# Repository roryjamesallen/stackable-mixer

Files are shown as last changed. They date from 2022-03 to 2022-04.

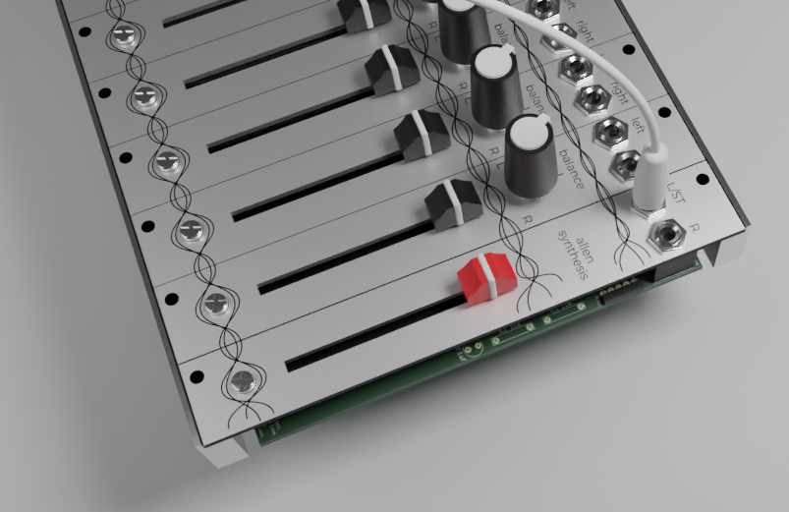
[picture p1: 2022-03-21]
extras/render.png

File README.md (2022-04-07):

# stackable-mixer
A versatile, affordable, free hardware, stereo mixer for Eurorack


  
Each input channel has either mono or stereo inputs, a balance control, a mute switch, and a volume control.
The output stage has a stereo TRS (headphone) output, but patching into the right input will break the normalling, allowing you to output stereo over two mono cables.
The output also has a mute switch and volume control, so you can easily mute your system or adjust the master volume depending on where your output is going.
  
Each input channel is passive, so can be made very affordably, although ±12V and Earth are available from the bus which carries the stereo signals, so future/user-developed input stages could be active, for example an input stage with an active EQ.
  
There is also of course the potential for alternative output stages, such as balanced 6.35mm or separate output and monitor outputs for headphone monitoring during a live set.

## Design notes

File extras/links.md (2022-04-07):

[female header](https://www.toby.co.uk/board-to-board-pcb-connectors/200mm-sockets/b13a-valcon-2mm-single-row-right-angle-socket-strip-43mm-profile/)

[slide potentiometer](https://www.mouser.co.uk/ProductDetail/Bourns/PTA4544-2010DPA103?qs=U%2FacTlguYxa%252BzXWV0%2FTcHg%3D%3D)

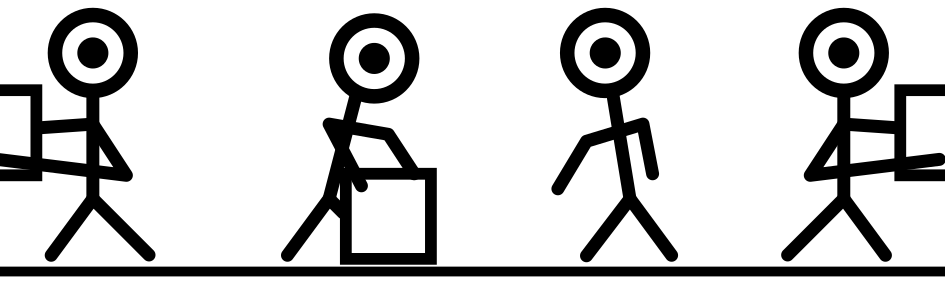
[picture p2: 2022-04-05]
extras/artwork/.svg2shenzhen-cache/images/F.SilkS_layer1.png

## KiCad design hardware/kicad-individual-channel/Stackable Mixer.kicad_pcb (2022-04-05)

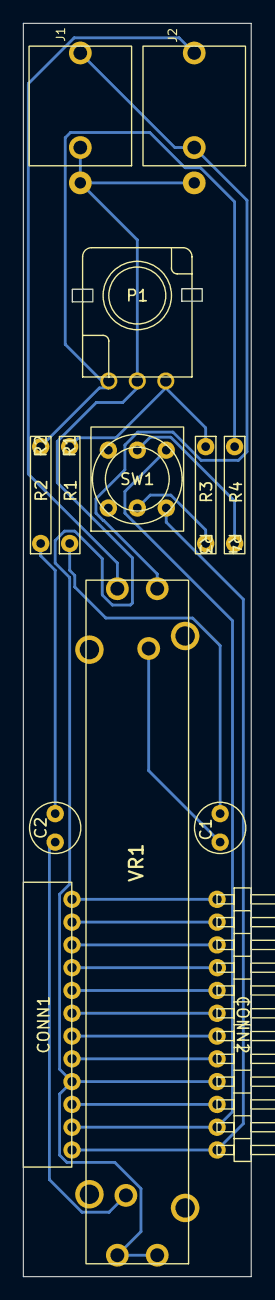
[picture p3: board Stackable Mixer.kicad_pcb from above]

Board: 2 copper layers, 20.0 x 110.0 mm, 13 parts (0 on the bottom side), 22 nets.

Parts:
C1, C2: 100nF; Capacitor Small Non-Polarised
CONN1: Header_2.0mm_Right_Angle_Female; Header 01x12 2.0mm Right Angle Female
CONN2: Header_2.0mm_Right_Angle_Male; Header 01x12 2.0mm Right Angle Male
J1: L/Mono; Thonkiconn Mono Jack
J2: R; Thonkiconn Mono Jack
P1: Potentiometer_9mm_Vertical_Linear; Potentiometer 9mm Vertical Linear
R1, R2: 100k; Resistor 0.25W Through-Hole
R3, R4: 4.7k; Resistor 0.25W Through-Hole
SW1: SW_DPDT_x2; Sub-Miniature Toggle Switch DPDT
VR1: Potentiometer_45mm_Slide_Audio_Dual; Potentiometer 45mm Slide Audio

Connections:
/+12V: CONN1.5, CONN2.8
/-12V: CONN1.3, CONN2.10
/LEFT BUS: CONN1.1, CONN2.12, SW1.1 (A)
/LEFT SIGNAL: R3.2, SW1.2 (B)
/RIGHT BUS: CONN1.2, CONN2.11, SW1.4 (A)
/RIGHT SIGNAL: R4.2, SW1.5 (B)
Earth: CONN1.4, CONN2.9, J1.1 (E), J1.2 (S), J2.1 (E), P1.2, VR1.1, VR1.4
unnamed: C1.1, VR1.5
unnamed: C1.2, R1.1
unnamed: C2.1, VR1.2
unnamed: C2.2, R2.1
unnamed: CONN1.6, CONN2.7
unnamed: CONN1.7, CONN2.6
unnamed: CONN1.8, CONN2.5
unnamed: CONN1.9, CONN2.4
unnamed: CONN1.10, CONN2.3
unnamed: CONN1.11, CONN2.2
unnamed: CONN1.12, CONN2.1
unnamed: J1.3 (T), J2.2 (S), VR1.6
unnamed: J2.3 (T), VR1.3
unnamed: P1.1, R2.2, R4.1
unnamed: P1.3, R1.2, R3.1

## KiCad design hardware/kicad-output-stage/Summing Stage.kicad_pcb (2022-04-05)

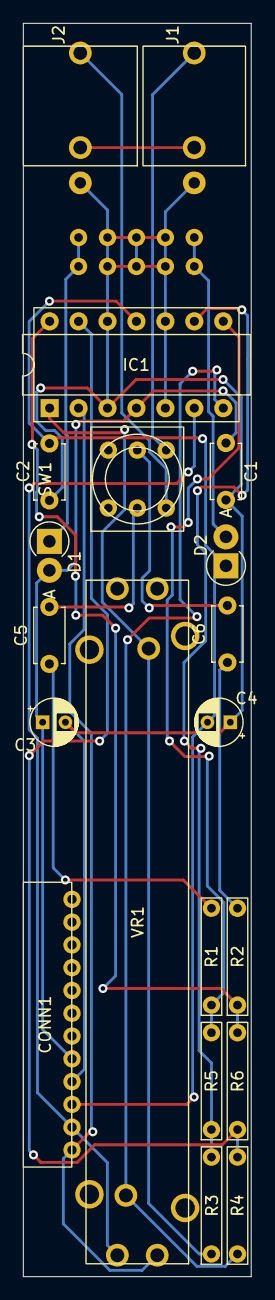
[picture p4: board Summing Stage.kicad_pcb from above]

Board: 2 copper layers, 20.0 x 110.0 mm, 21 parts (1 on the bottom side), 18 nets.

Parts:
C1, C2, C5, C6: 100n; C_Disc_D4.7mm_W2.5mm_P5.00mm
C3, C4: 10u; CP_Radial_D4.0mm_P2.00mm
CONN1: Header_2.0mm_Right_Angle_Female; Header 01x12 2.0mm Right Angle Female
D1, D2: DIODE; D_DO-41_SOD81_P2.54mm_Vertical_AnodeUp
IC1: TL074; DIP-14 IC Socket
J1: Thonkiconn_Mono_Jack; Thonkiconn Mono Jack
J2: AudioJack3; Thonkiconn Stereo Jack
PowerHeader1: Conn_02x05_Counter_Clockwise; Eurorack Power Header
R1, R2: 1k; Resistor 0.25W Through-Hole
R3, R4, R5, R6: 4.7k; Resistor 0.25W Through-Hole
SW1: SW_DPDT_x2; Sub-Miniature Toggle Switch DPDT
VR1: Potentiometer_45mm_Slide_Audio_Dual; Potentiometer 45mm Slide Audio

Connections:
+12V: C1.1, C3.1, CONN1.5, D1.2 (K), IC1.4 (V+)
-12V: C2.2, C4.2, CONN1.3, D2.1 (A), IC1.11 (V-)
Earth: C1.2, C2.1, C3.2, C4.1, CONN1.4, IC1.3 (+), IC1.5 (+), IC1.10 (+), IC1.12 (+), J1.1 (E), PowerHeader1.3, PowerHeader1.4, PowerHeader1.5, PowerHeader1.6, PowerHeader1.7, PowerHeader1.8
unnamed: C5.1, R1.2
unnamed: C5.2, SW1.2 (B)
unnamed: C6.1, R2.2
unnamed: C6.2, SW1.5 (B)
unnamed: CONN1.1, IC1.2 (-), VR1.4
unnamed: CONN1.2, IC1.6 (-), VR1.1
unnamed: D1.1 (A), PowerHeader1.9, PowerHeader1.10
unnamed: D2.2 (K), PowerHeader1.1, PowerHeader1.2
unnamed: IC1.1, R3.1, VR1.5
unnamed: IC1.7, R4.1, VR1.2
unnamed: IC1.8, R1.1, R5.2
unnamed: IC1.9 (-), R3.2, R5.1
unnamed: IC1.13 (-), R4.2, R6.1
unnamed: IC1.14, R2.1, R6.2
R OUT: J1.3 (T), SW1.4 (A)

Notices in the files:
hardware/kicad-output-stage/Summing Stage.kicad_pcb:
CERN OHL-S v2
